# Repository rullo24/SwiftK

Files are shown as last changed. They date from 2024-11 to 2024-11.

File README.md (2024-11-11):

# SwiftK
SwiftK is an open-source project for creating a customizable macro keypad that integrates seamlessly with your workflow. Designed for developers, gamers, and productivity enthusiasts, SwiftK provides a streamlined way to enhance your interaction with your computer through user-defined macros.

## About SwiftK
SwiftK was created to make repetitive tasks more efficient by providing a versatile macro keypad solution. With customizable keys, users can map complex command sequences or simple shortcuts, tailored to their needs. SwiftK aims to make interactions more productive and enjoyable for users in programming, gaming, content creation, and more.

This GitHub repo holds the KiCAD files required for the creation of this electronic board.

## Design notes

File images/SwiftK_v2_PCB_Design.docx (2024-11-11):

# Notes

- All unused space has been filled in with GND.
- Have used a small +5V plane near USB-C (shown in layer 3) and a small +1.1V plane near left of MCU (also shown in layer 3).
- All vias are specifically layered so that they only go from the top layer to their respective layer (excluding GND – these vias pass all the way through). For example, a 3.3V via will go from layer 1 – 2 but not drill through 3 or 4.

# Layer 1 – Front Layer

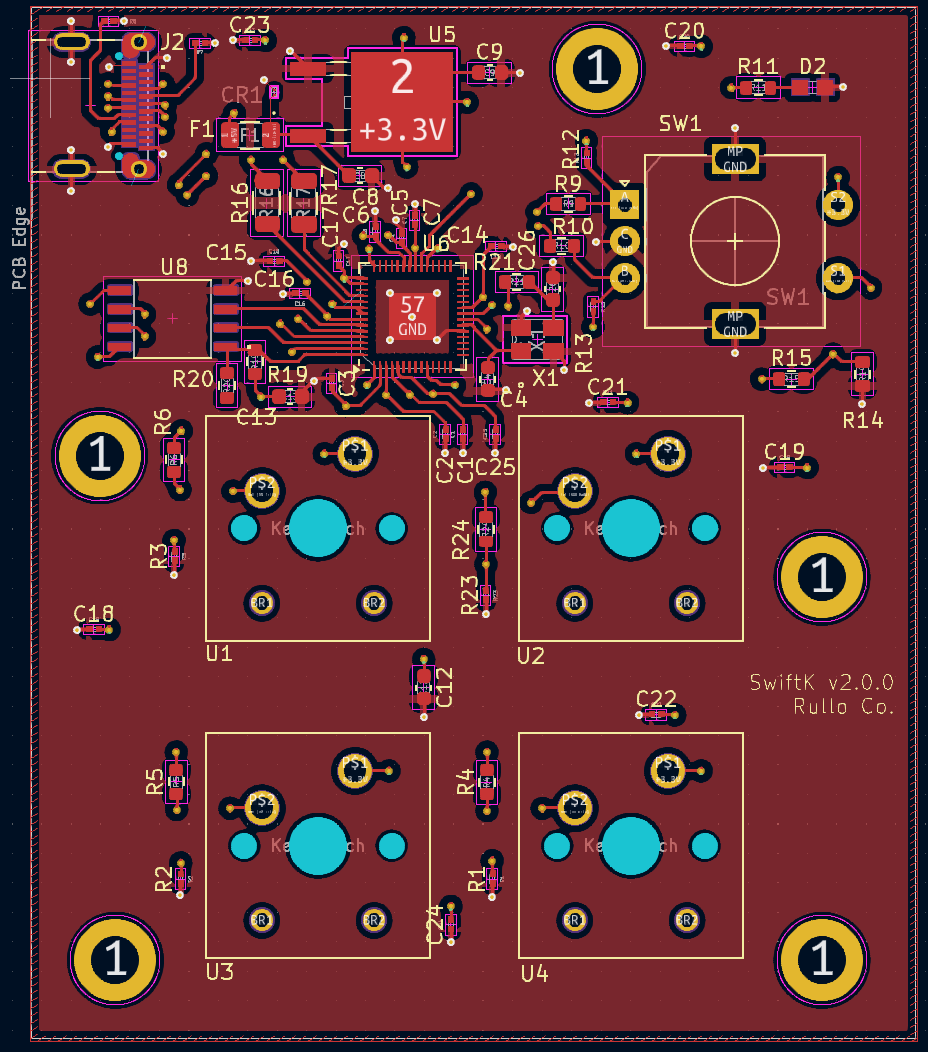
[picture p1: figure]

# Layer 2 – 3.3V

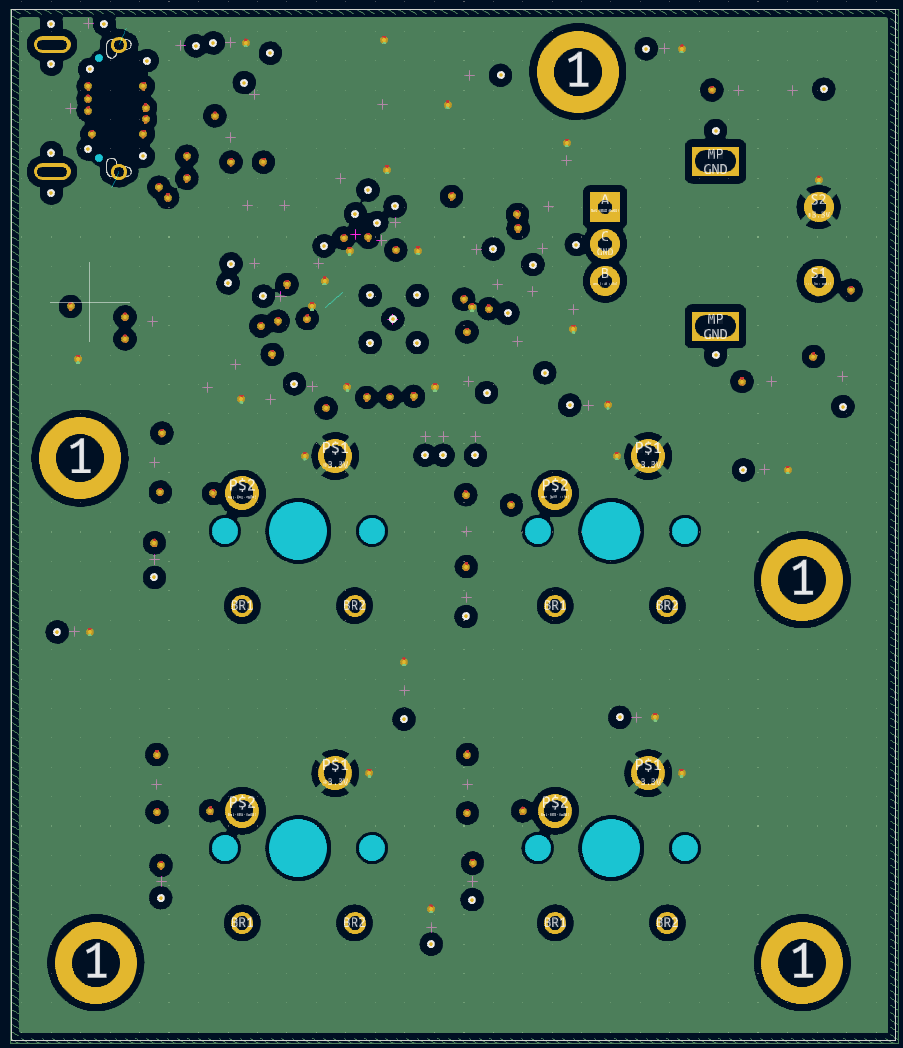
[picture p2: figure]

# Layer 3 – Inner Signals

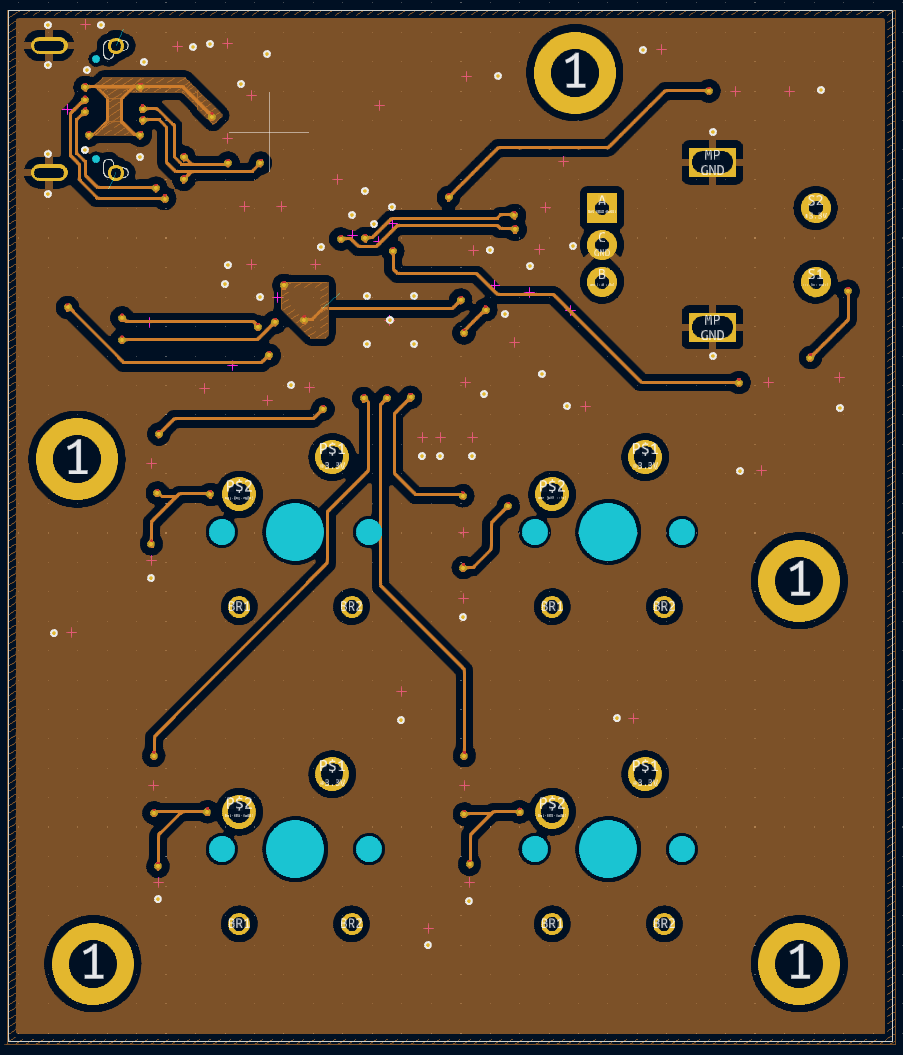
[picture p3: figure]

# Layer 4 - GND

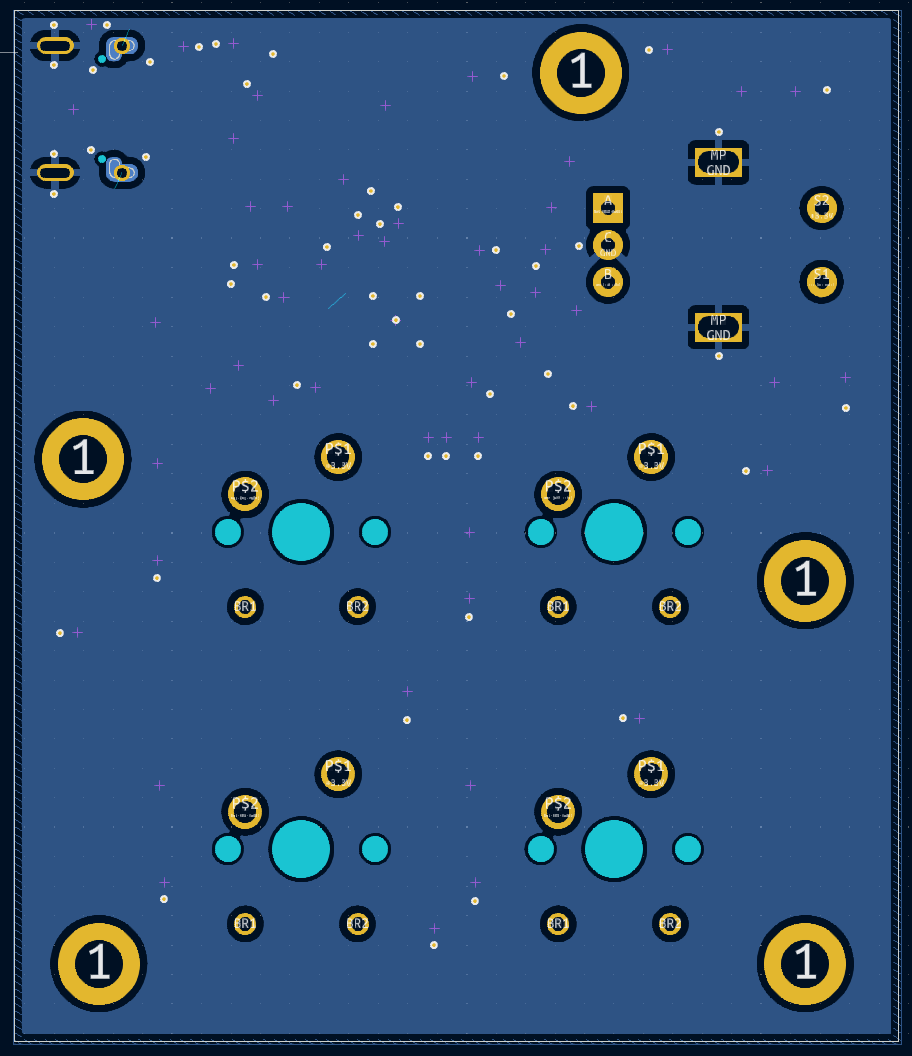
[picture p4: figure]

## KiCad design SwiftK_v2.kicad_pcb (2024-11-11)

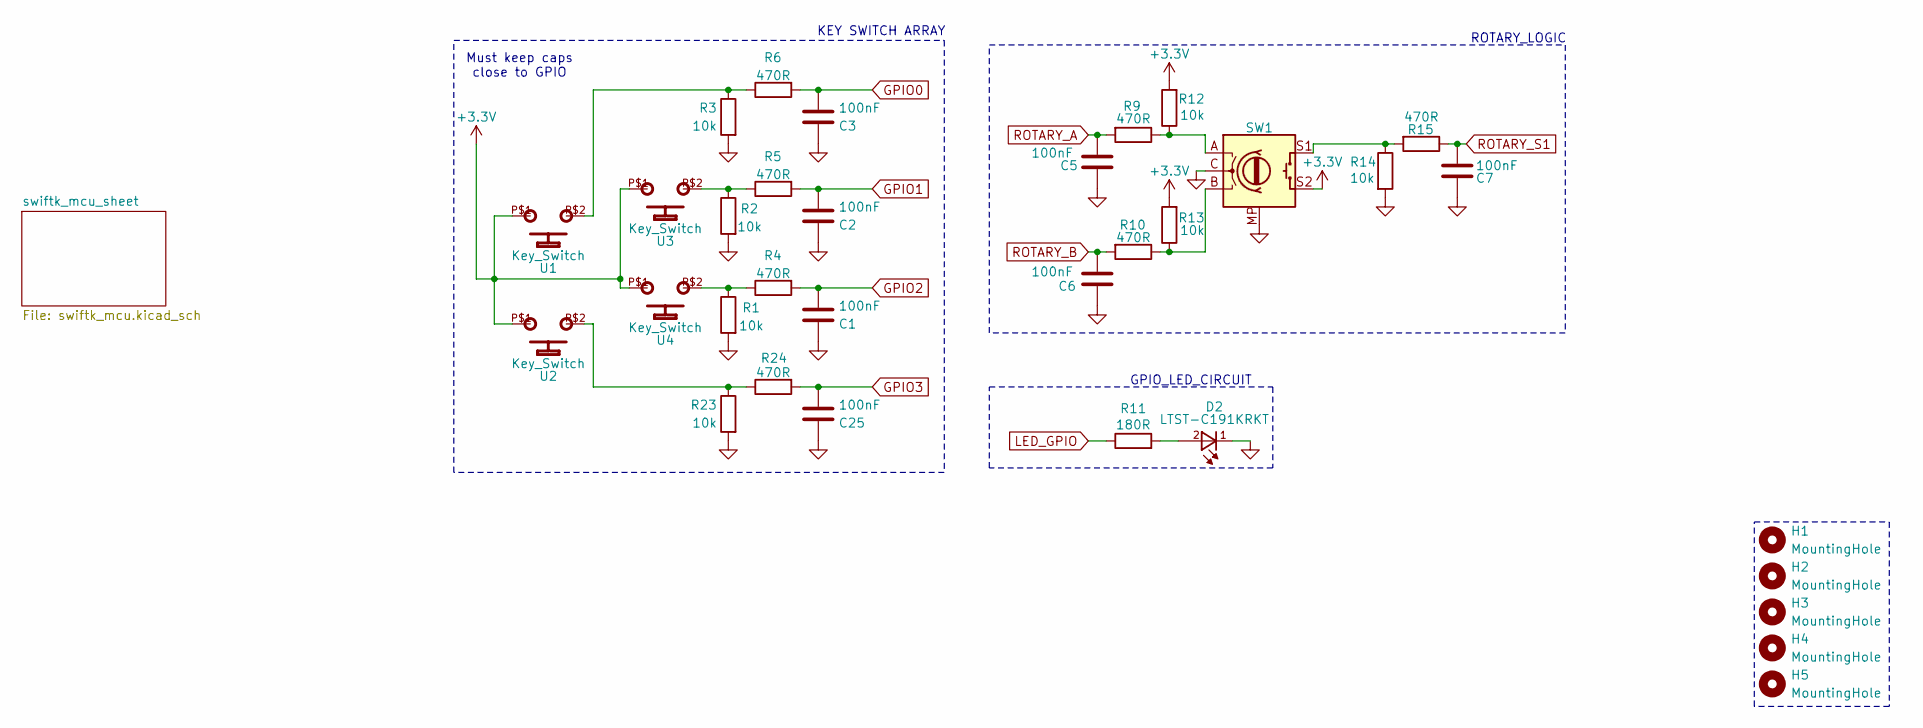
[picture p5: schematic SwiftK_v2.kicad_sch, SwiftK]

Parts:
C1, C2, C3, C5, C6, C7, C25: 100nF; C_0201_0603Metric; JLCPCB Part# C76928
D2: LTST-C191KRKT; liteon_LTST-C191KRKT; JLCPCB Part# C125099
H1, H2, H3, H4, H5: MountingHole; MountingHole_3.2mm_M3_DIN965_Pad
R1, R2, R3, R12, R13, R23: 10k; R_0201_0603Metric; JLCPCB Part# C100126
R4, R5, R6, R9, R10, R15, R24: 470R; R_0603_1608Metric; JLCPCB Part# C374403
R11: 180R; R_0603_1608Metric; JLCPCB Part# C25210
R14: 10k; R_0603_1608Metric; JLCPCB Part# C15401
SW1: RotaryEncoder_Switch_MP; RotaryEncoder_Alps_EC11E-Switch_Vertical_H20mm
U1, U2, U3, U4: Key_Switch; CHERRY_MX1A-11NN_SWITCH

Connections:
+3.3V: R12.2, R13.2, SW1.S2, U1.P$1, U2.P$1, U3.P$1, U4.P$1; also elsewhere on the board
GND: C1.1, C2.1, C3.1, C5.2, C6.2, C7.2, C25.1, D2.1, R1.2, R2.2, R3.2, R14.2, R23.2, SW1.C, SW1.MP; also elsewhere on the board
GPIO0: C3.2, R6.2; also elsewhere on the board
GPIO1: C2.2, R5.2; also elsewhere on the board
GPIO2: C1.2, R4.2; also elsewhere on the board
GPIO3: C25.2, R24.2; also elsewhere on the board
LED_GPIO: R11.1; also elsewhere on the board
unnamed: D2.2, R11.2
unnamed: R1.1, R4.1, U4.P$2
unnamed: R2.1, R5.1, U3.P$2
unnamed: R3.1, R6.1, U1.P$2
unnamed: R10.1, R13.1, SW1.B
unnamed: R9.1, R12.1, SW1.A
unnamed: R14.1, R15.2, SW1.S1
unnamed: R23.1, R24.1, U2.P$2
ROTARY_A: C5.1, R9.2; also elsewhere on the board
ROTARY_B: C6.1, R10.2; also elsewhere on the board
ROTARY_S1: C7.1, R15.1; also elsewhere on the board

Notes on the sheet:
Must keep caps close to GPIO
GPIO_LED_CIRCUIT
ROTARY_LOGIC
KEY SWITCH ARRAY

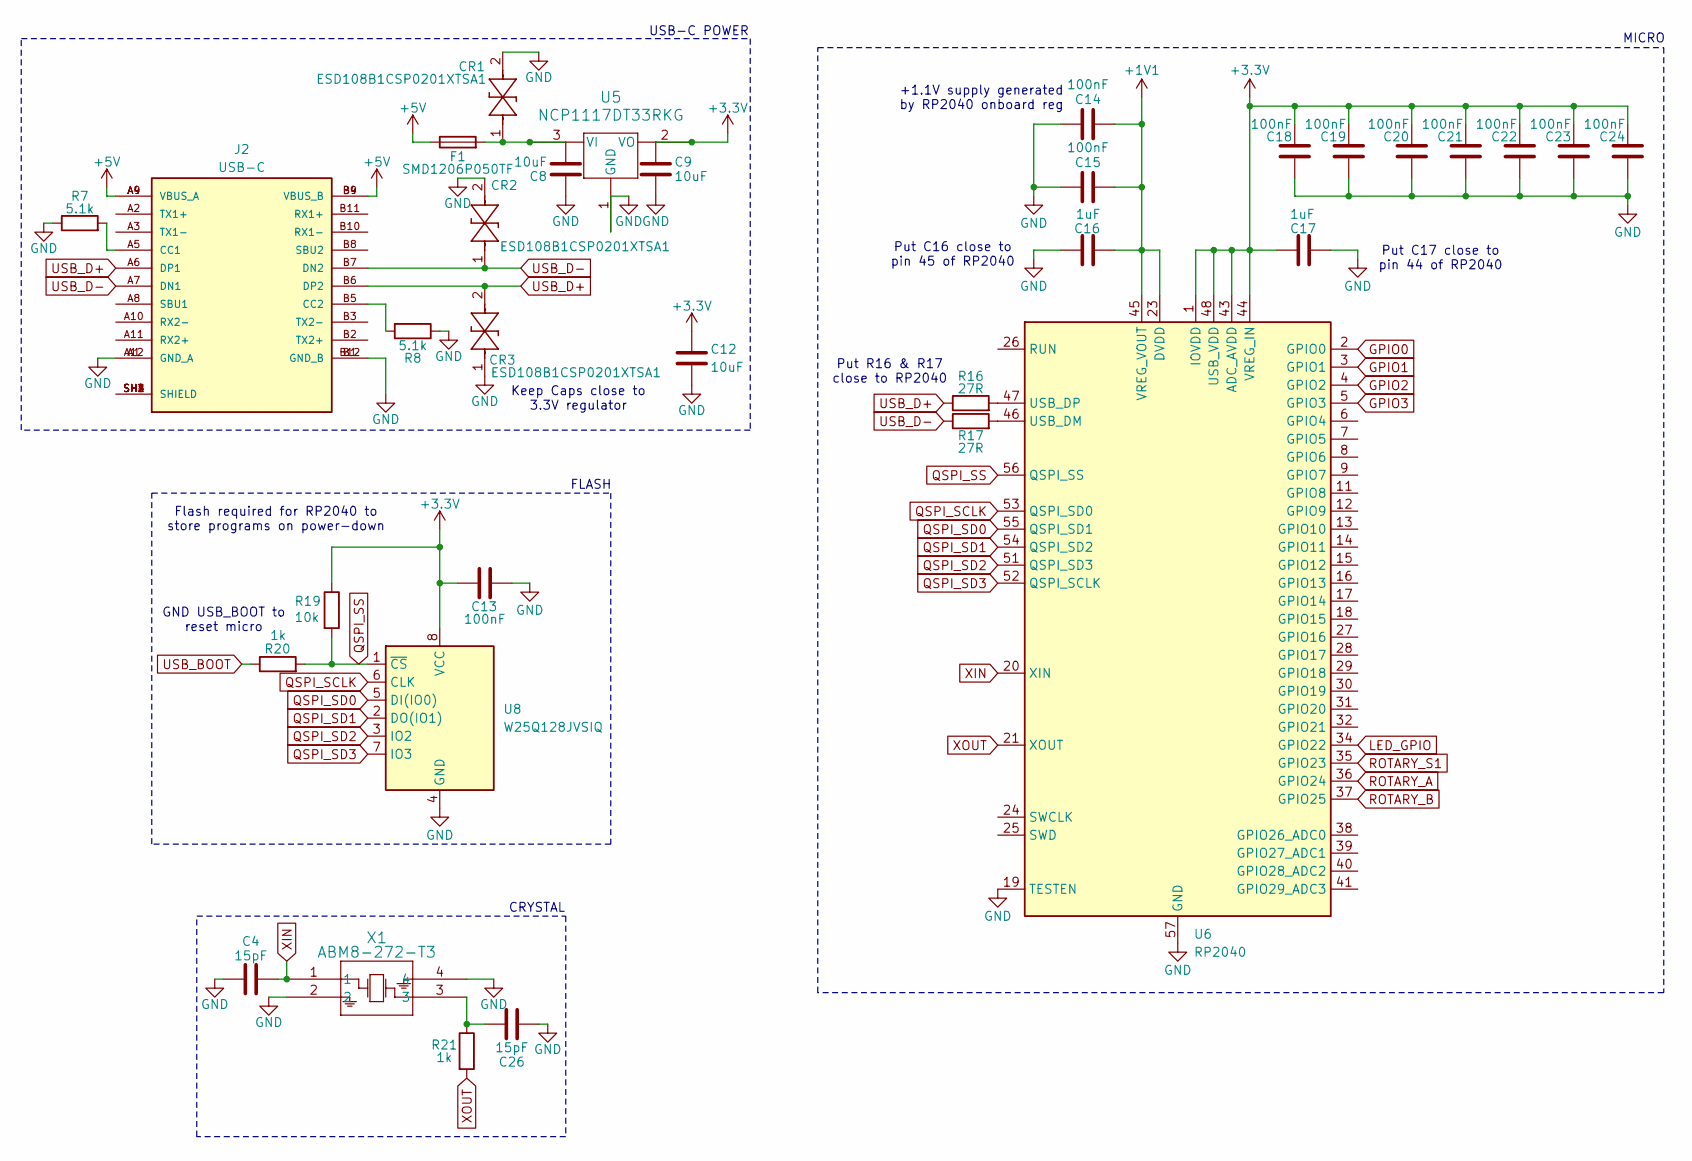
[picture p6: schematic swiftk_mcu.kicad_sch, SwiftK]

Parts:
C4, C26: 15pF; C_0603_1608Metric; JLCPCB Part# C1644
C8, C9, C12: 10uF; C_0603_1608Metric; JLCPCB Part# C18800
C13, C14, C15, C18, C19, C20, C21, C22, C23, C24: 100nF; C_0201_0603Metric; JLCPCB Part# C76928
C16, C17: 1uF; C_0201_0603Metric; JLCPCB Part# C76929
CR1, CR2, CR3: ESD108B1CSP0201XTSA1; Infineon_ESD108B1CSP0201XTSA1_L; JLCPCB Part# C672056
F1: SMD1206P050TF; Fuse_1206_3216Metric; JLCPCB Part# C20799
J2: USB-C; te_connectivity_2345986-1; JLCPCB Part# C5382687
R7, R8: 5.1k; R_0201_0603Metric; JLCPCB Part# C100142
R16, R17: 27R; R_1206_3216Metric; JLCPCB Part# C17946
R19: 10k; R_0603_1608Metric; JLCPCB Part# C15401
R20, R21: 1k; R_0603_1608Metric; JLCPCB Part# C51218
U5: NCP1117DT33RKG; onsemi_NCP1117DT33RKG_S; JLCPCB Part# C88234
U6: RP2040; QFN-56-1EP_7x7mm_P0.4mm_EP3.2x3.2mm; JLCPCB Part# C2040
U8: W25Q128JVSIQ; Winbond_Elec_W25Q128JVSIQ; JLCPCB Part# C97521
X1: ABM8-272-T3; Abracon_LLC_ABM8-272-T3; JLCPCB Part# C20625731

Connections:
+1V1: C14.2, C15.2, C16.1, U6.23 (DVDD), U6.45 (VREG_VOUT), U6.50 (DVDD)
+3.3V: C9.1, C12.1, C13.2, C17.2, C18.2, C19.2, C20.2, C21.2, C22.2, C23.2, C24.2, R19.1, U5.2 (VO), U6.1 (IOVDD), U6.10 (IOVDD), U6.22 (IOVDD), U6.33 (IOVDD), U6.42 (IOVDD), U6.43 (ADC_AVDD), U6.44 (VREG_IN), U6.48 (USB_VDD), U6.49 (IOVDD), U8.8 (VCC); also elsewhere on the board
+5V: F1.1, J2.A4 (VBUS_A), J2.A9 (VBUS_A), J2.B4 (VBUS_B), J2.B9 (VBUS_B)
GND: C4.1, C8.1, C9.2, C12.2, C13.1, C14.1, C15.1, C16.2, C17.1, C18.1, C19.1, C20.1, C21.1, C22.1, C23.1, C24.1, C26.1, CR1.2, CR2.2, CR3.1, J2.A1 (GND_A), J2.A12 (GND_A), J2.B1 (GND_B), J2.B12 (GND_B), R7.1, R8.1, U5.1 (GND), U6.19 (TESTEN), U6.57 (GND), U8.4 (GND), X1.2, X1.4; also elsewhere on the board
GPIO0: U6.2 (GPIO0); also elsewhere on the board
GPIO1: U6.3 (GPIO1); also elsewhere on the board
GPIO2: U6.4 (GPIO2); also elsewhere on the board
GPIO3: U6.5 (GPIO3); also elsewhere on the board
LED_GPIO: U6.34 (GPIO22); also elsewhere on the board
unnamed: C26.2, R21.1, X1.3
unnamed: J2.A5 (CC1), R7.2
unnamed: J2.B5 (CC2), R8.2
unnamed: J2.SH1 (SHIELD), J2.SH2 (SHIELD), J2.SH3 (SHIELD), J2.SH4 (SHIELD)
unnamed: C8.2, CR1.1, F1.2, U5.3 (VI)
unnamed: R17.2, U6.46 (USB_DM)
unnamed: R16.2, U6.47 (USB_DP)
QSPI_SCLK: U6.53 (QSPI_SD0), U8.6 (CLK)
QSPI_SD0: U6.55 (QSPI_SD1), U8.5 (DI(IO0))
QSPI_SD1: U6.54 (QSPI_SD2), U8.2 (DO(IO1))
QSPI_SD2: U6.51 (QSPI_SD3), U8.3 (IO2)
QSPI_SD3: U6.52 (QSPI_SCLK), U8.7 (IO3)
QSPI_SS: R19.2, R20.2, U6.56 (QSPI_SS), U8.1 (~CS)
ROTARY_A: U6.36 (GPIO24); also elsewhere on the board
ROTARY_B: U6.37 (GPIO25); also elsewhere on the board
ROTARY_S1: U6.35 (GPIO23); also elsewhere on the board
USB_BOOT: R20.1
USB_D+: CR3.2, J2.A6 (DP1), J2.B6 (DP2), R16.1
USB_D-: CR2.1, J2.A7 (DN1), J2.B7 (DN2), R17.1
XIN: C4.2, U6.20 (XIN), X1.1
XOUT: R21.2, U6.21 (XOUT)

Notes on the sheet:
Keep Caps close to 3.3V regulator
USB-C POWER
Put C16 close to pin 45 of RP2040
Flash required for RP2040 to store programs on power-down
FLASH
CRYSTAL
GND USB_BOOT to reset micro
MICRO
Put C17 close to pin 44 of RP2040
Put R16 & R17 close to RP2040
+1.1V supply generated by RP2040 onboard reg

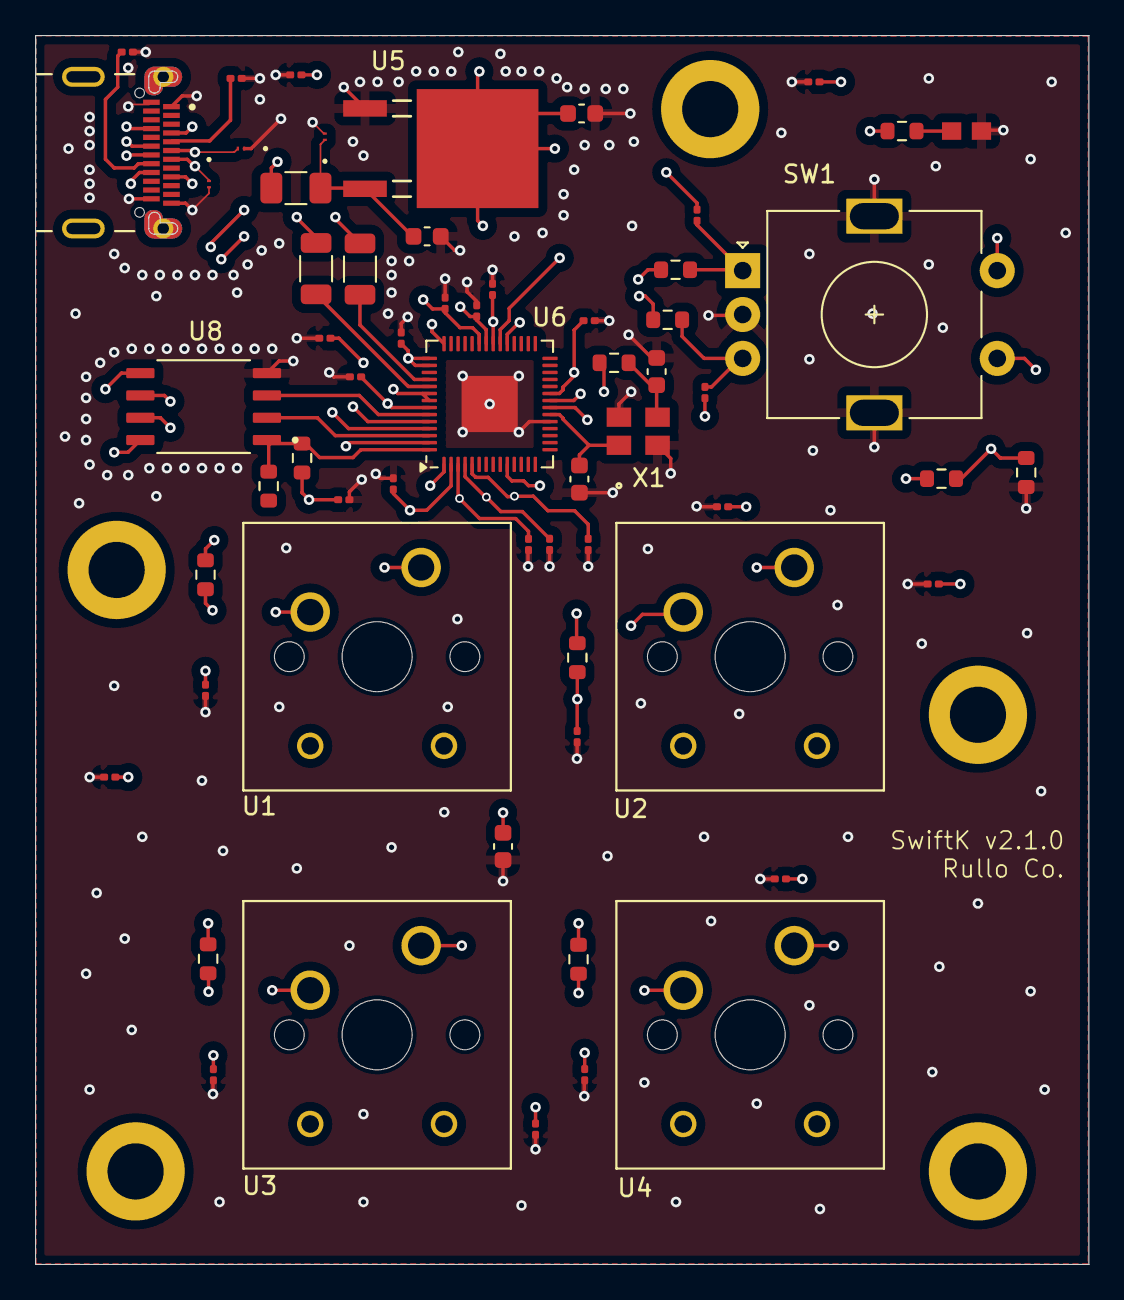
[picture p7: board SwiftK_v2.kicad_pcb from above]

Board: 4 copper layers, 60.0 x 70.0 mm, 66 parts (0 on the bottom side), 37 nets.
